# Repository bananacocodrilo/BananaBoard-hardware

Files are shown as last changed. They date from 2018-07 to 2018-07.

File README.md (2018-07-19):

# BananaBoard-hardware

This is still under development and subject to changes.

Split wireless keyboard based on the [mitosis](https://github.com/reversebias/mitosis-hardware) and the [chimera](https://github.com/GlenPickle/Chimera).

The goal is to make boards easy to solder and compatible with existing cases for popular keybards as "let's split" or "iris keyboard" and a miniboard for handwired builds.

I'll also publish a fork of their firmware as well since I need to use a matrix configuration instead of a "pin per switch", furthermore I'll add battery measure and underglow leds.

I haven't make a PCB in a while and is my first time using kicad so I'm learning as a I go.

Current state:
-
 - "Finished" schematic: I like how it is right now and it will probably stay like this.
 - "Finished" a first version for handwired builds (it fits in 24mmx50mm so I added 2 per board).
 - Second version of the 40% split PCB, I think is compatible with the "lets split" case but it isn't reversible so I'll need to create the "right hand" too.

Next steps: 
-
 - Decide a footprint for the switches (right now I'm not sure which footprint works with which switch).
 - (Currently working) Create the right hand of the lets split.
 - Investigate other lipo charger circuits. I've ordered a few cheap micro usb ones since I couldn't find reliable size info.
 - Start the firmware modifications.

Ortho 40% board (left hand):
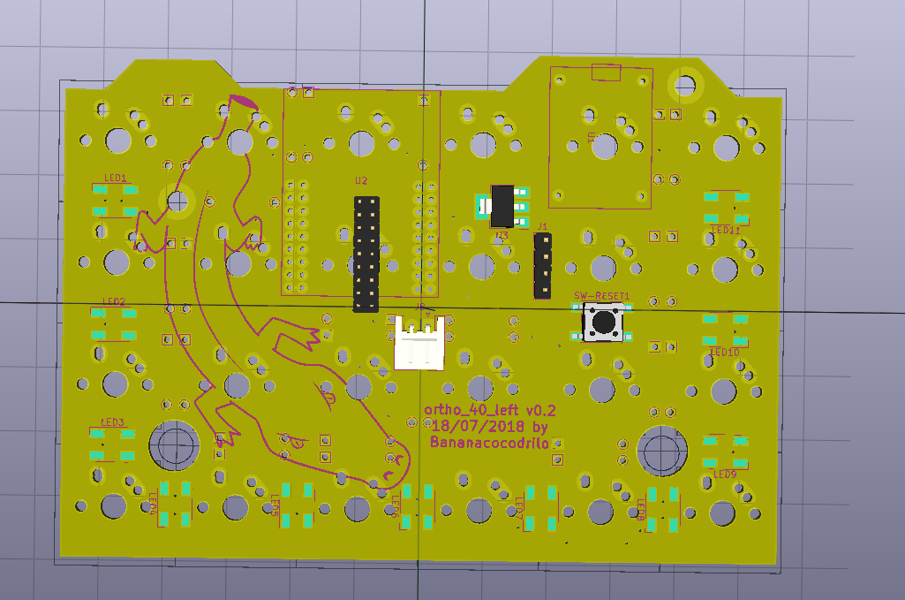
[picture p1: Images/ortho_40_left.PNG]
pcb image


Handwired keyboards board:
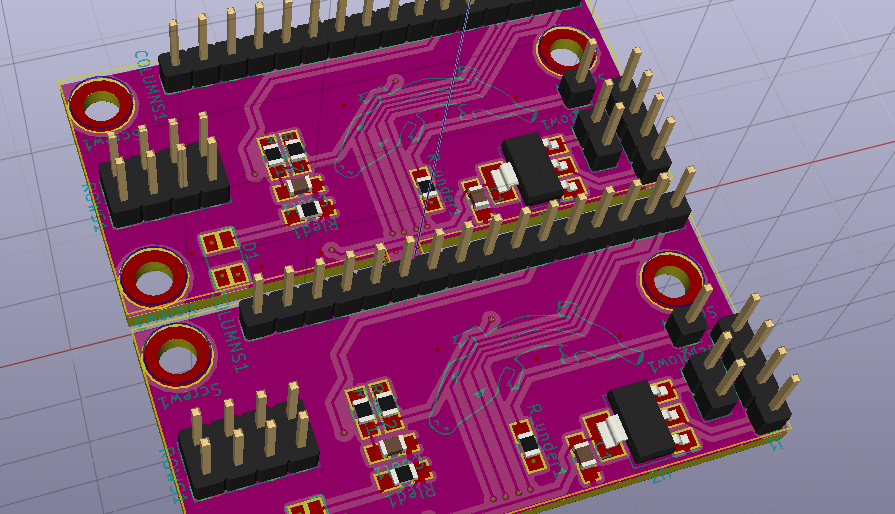
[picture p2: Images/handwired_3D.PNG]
handwired


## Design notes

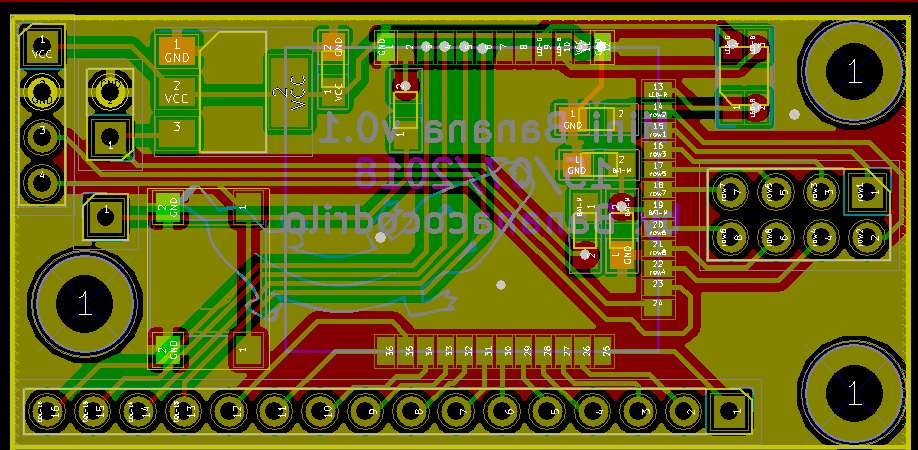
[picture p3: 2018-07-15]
Images/handwired.PNG

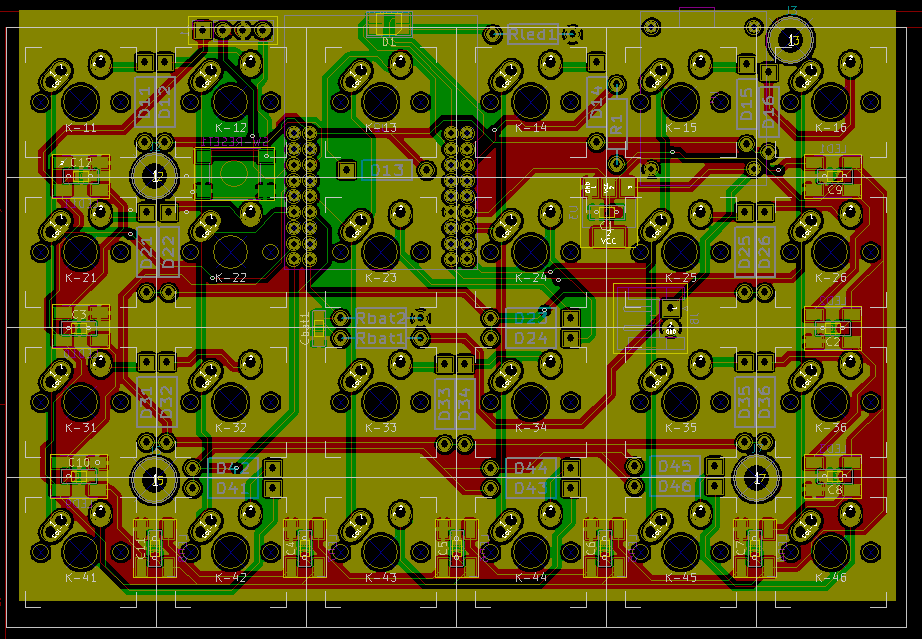
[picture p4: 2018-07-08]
Images/pcb.PNG

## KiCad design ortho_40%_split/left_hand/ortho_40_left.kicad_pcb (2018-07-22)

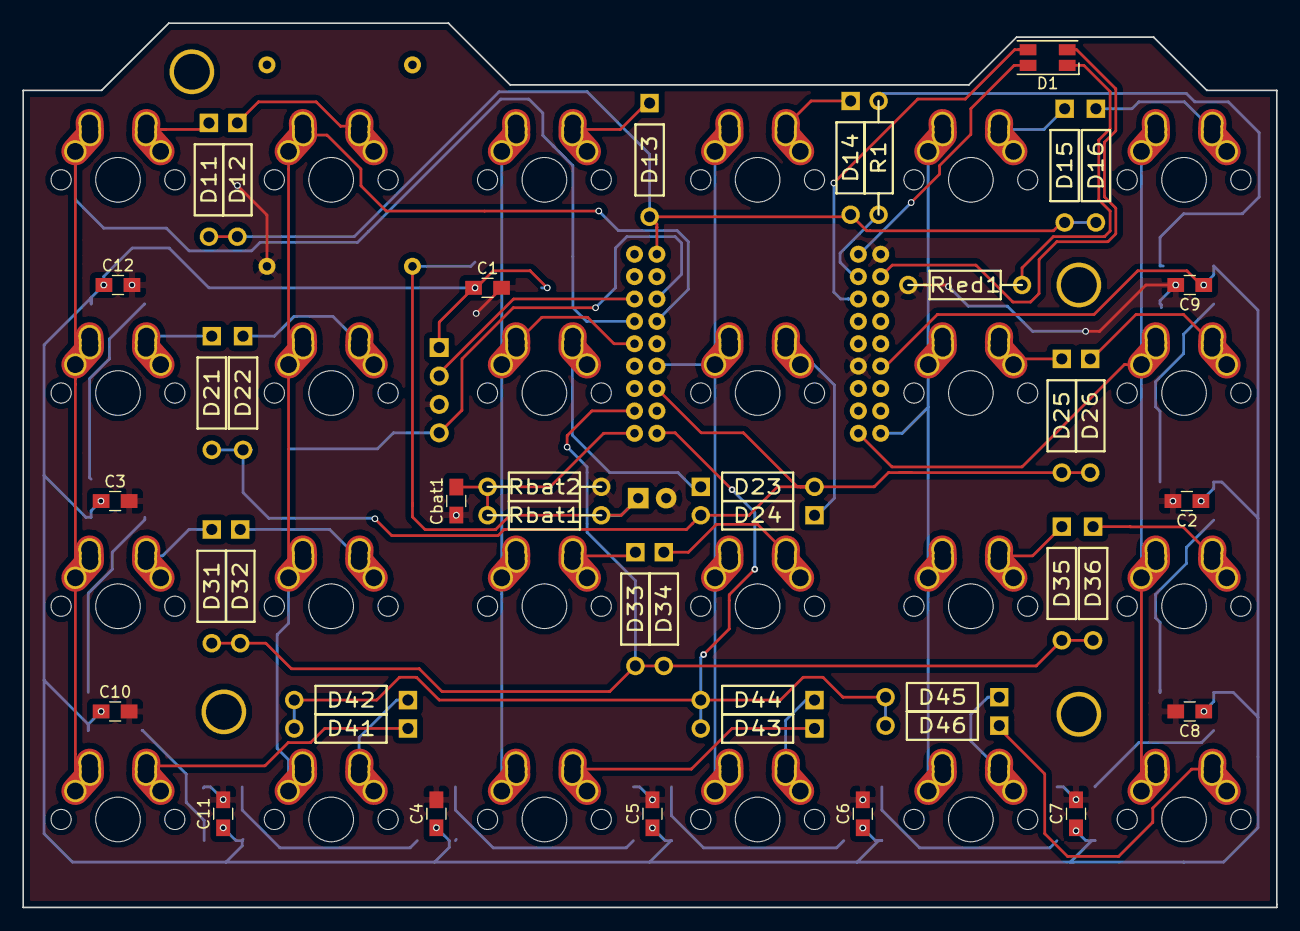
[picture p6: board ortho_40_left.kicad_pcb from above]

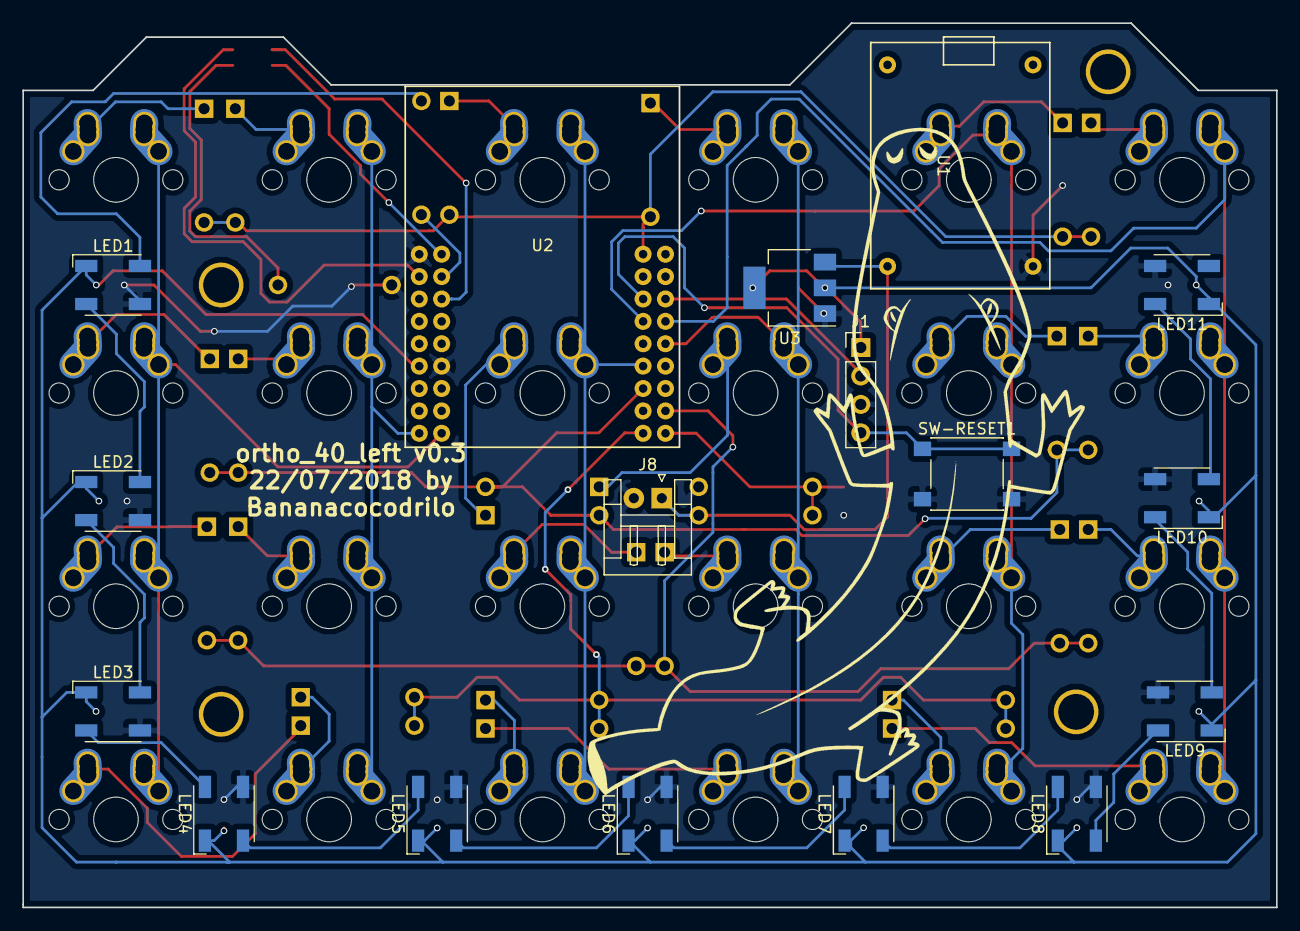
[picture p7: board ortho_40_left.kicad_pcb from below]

Board: 2 copper layers, 112.0 x 79.0 mm, 87 parts (17 on the bottom side), 56 nets.

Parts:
C1: 47uF; C_0805_HandSoldering
C2, C3, C4, C5, C6, C7, C8, C9, C10, C11, C12: 0.1uF; C_0805_HandSoldering
Cbat1: 22n; C_0805_HandSoldering
D1: LED_BAT; LED_RGB_1210
D11, D12, D13, D14, D15, D16, D21, D22, D23, D24, D25, D26, D31, D32, D33, D34, D35, D36, D41, D42, D43, D44, D45, D46: D; DIODE
J1: prog_pins; Pin_Header_Straight_1x04_Pitch2.54mm
J2, J3, J5, J7: Conn_01x01; HOLE_M3
J8: Conn-Battery; JST_EH_S02B-EH_02x2.50mm_Angled
K-11, K-12, K-13, K-14, K-15, K-16, K-21, K-22, K-23, K-24, K-25, K-26, K-31, K-32, K-33, K-34, K-35, K-36, K-41, K-42, K-43, K-44, K-45, K-46: KEYSW; Hybrid_PCB_100H_Dual_hole
LED1, LED2, LED3, LED4, LED5, LED6, LED7, LED8, LED9, LED10, LED11: WS2812B; LED_RGB_5050-4
R1: 470; RESISTOR
Rbat1: 10M; RESISTOR
Rbat2: 2.2M; RESISTOR
Rled1: 470; RESISTOR
SW-RESET1: SW_PUSH; SW_SPST_PTS645
U1: cargador-USB; cargador-mini-usb
U2: core51822; core51822-through-hole
U3: LM1117-3.3; SOT-223-3_TabPin2

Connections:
BAT-M: Cbat1.2, Rbat1.1, Rbat2.2, U2.36
GND: C1.2, C2.2, C3.2, C4.2, C5.2, C6.2, C7.2, C8.2, C9.2, C10.2, C11.2, C12.2, Cbat1.1, J1.3, J8.2, LED1.3, LED2.3, LED3.3, LED4.3, LED5.3, LED6.3, LED7.3, LED8.3, LED9.3, LED10.3, LED11.3, Rbat2.1, Rled1.1, SW-RESET1.2, U1.3, U2.1, U2.12, U3.1
LED-B: D1.4, U2.2
LED-G: D1.3, U2.6
LED-R: D1.2, U2.3
unnamed: D1.1, Rled1.2
unnamed: D11.2, K-11.2
unnamed: D12.2, K-12.2
unnamed: D13.2, K-13.2
unnamed: D14.2, K-14.2
unnamed: D15.2, K-15.2
unnamed: D16.2, K-16.2
unnamed: D21.2, K-21.2
unnamed: D22.2, K-22.2
unnamed: D23.2, K-23.2
unnamed: D24.2, K-24.2
unnamed: D25.2, K-25.2
unnamed: D26.2, K-26.2
unnamed: D31.2, K-31.2
unnamed: D32.2, K-32.2
unnamed: D33.2, K-33.2
unnamed: D34.2, K-34.2
unnamed: D35.2, K-35.2
unnamed: D36.2, K-36.2
unnamed: D41.2, K-41.2
unnamed: D42.2, K-42.2
unnamed: D43.2, K-43.2
unnamed: D44.2, K-44.2
unnamed: D45.2, K-45.2
unnamed: D46.2, K-46.2
unnamed: J1.2, U2.24
unnamed: J1.4, SW-RESET1.1, U2.23
unnamed: J8.1, Rbat1.2, U1.2, U3.3
unnamed: LED1.2, LED2.4
unnamed: LED1.4, R1.1
unnamed: LED2.2, LED3.4
unnamed: LED3.2, LED4.4
unnamed: LED4.2, LED5.4
unnamed: LED5.2, LED6.4
unnamed: LED6.2, LED7.4
unnamed: LED7.2, LED8.4
unnamed: LED8.2, LED9.4
unnamed: LED10.2, LED11.4
VCC: C1.1, C2.1, C3.1, C4.1, C5.1, C6.1, C7.1, C8.1, C9.1, C10.1, C11.1, C12.1, J1.1, LED1.1, LED2.1, LED3.1, LED4.1, LED5.1, LED6.1, LED7.1, LED8.1, LED9.1, LED10.1, LED11.1, U2.11, U3.2
col-1: K-11.1, K-21.1, K-31.1, K-41.1, U2.26
col-2: K-12.1, K-22.1, K-32.1, K-42.1, U2.25
col-3: K-13.1, K-23.1, K-33.1, K-43.1, U2.28
col-4: K-14.1, K-24.1, K-34.1, K-44.1, U2.29
col-5: K-15.1, K-25.1, K-35.1, K-45.1, U2.17
col-6: K-16.1, K-26.1, K-36.1, K-46.1, U2.18
row-1: D11.1, D12.1, D13.1, D14.1, D15.1, D16.1, U2.19
row-2: D21.1, D22.1, D23.1, D24.1, D25.1, D26.1, U2.31
row-3: D31.1, D32.1, D33.1, D34.1, D35.1, D36.1, U2.34
row-4: D41.1, D42.1, D43.1, D44.1, D45.1, D46.1, U2.35
underglow: R1.2, U2.4
underglowAux: LED9.2, LED10.4

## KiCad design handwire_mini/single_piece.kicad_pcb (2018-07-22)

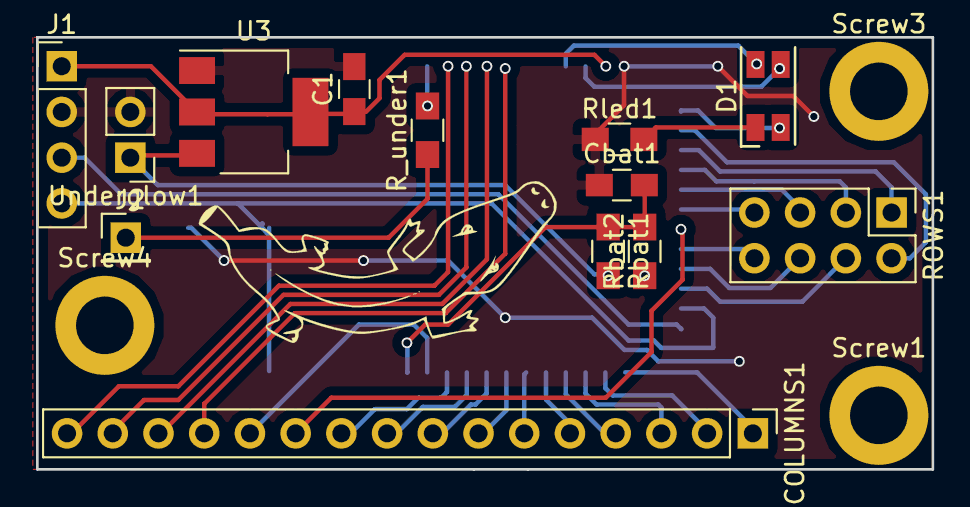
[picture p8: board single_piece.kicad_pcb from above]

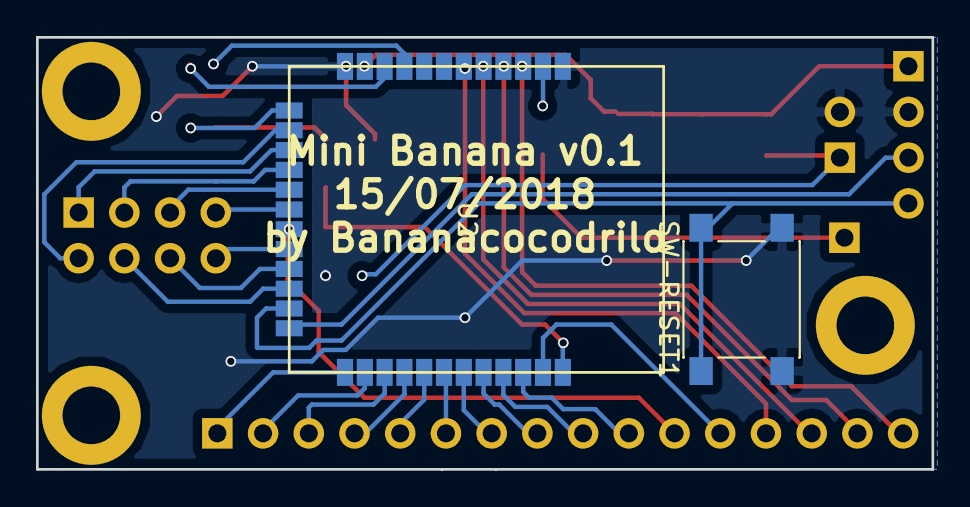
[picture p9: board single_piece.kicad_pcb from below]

Board: 2 copper layers, 49.8 x 24.0 mm, 18 parts (2 on the bottom side), 36 nets.

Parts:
C1: 47uF; C_0805_HandSoldering
COLUMNS1: Pin_Header_Straight_1x16_Pitch2.54mm
Cbat1: 22n; C_0805_HandSoldering
D1: LED_BAT; LED_RGB_1210
J1: prog_pins; Pin_Header_Straight_1x04_Pitch2.54mm
J2: Lipo; Pin_Header_Straight_1x02_Pitch2.54mm
ROWS1: ROWS; Pin_Header_Straight_2x04_Pitch2.54mm
R_under1: 470; R_0805_HandSoldering
Rbat1: 10M; R_0805_HandSoldering
Rbat2: 2.2M; R_0805_HandSoldering
Rled1: 470; R_0805_HandSoldering
SW-RESET1: SW_PUSH; SW_SPST_PTS645
Screw1, Screw3, Screw4: Screw; MountingHole_3.2mm_M3_ISO14580_Pad
U2: core51822; cpre51822-smd
U3: LM1117-3.3; SOT-223-3_TabPin2
Underglow1: TO_WS2812b; Pin_Header_Straight_1x01_Pitch2.54mm

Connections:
BAT-M: Cbat1.2, Rbat1.1, Rbat2.2, U2.36
COL-13: COLUMNS1.13, U2.6
COL-14: COLUMNS1.14, U2.5
COL-15: COLUMNS1.15, U2.4
COL-16: COLUMNS1.16, U2.3
GND: C1.2, Cbat1.1, J1.2, J2.2, Rbat2.1, Rled1.1, SW-RESET1.2, U2.1, U2.12, U3.1
LED-B: D1.3, U2.10
LED-G: D1.4, U2.9
LED-R: D1.2, U2.13
unnamed: COLUMNS1.1, U2.25
unnamed: COLUMNS1.2, U2.26
unnamed: COLUMNS1.3, U2.27
unnamed: COLUMNS1.4, U2.28
unnamed: COLUMNS1.5, U2.29
unnamed: COLUMNS1.6, U2.30
unnamed: COLUMNS1.7, U2.31
unnamed: COLUMNS1.8, U2.32
unnamed: COLUMNS1.9, U2.33
unnamed: COLUMNS1.10, U2.34
unnamed: COLUMNS1.12, U2.35
unnamed: D1.1, Rled1.2
unnamed: J1.3, U2.24
unnamed: J1.4, SW-RESET1.1, U2.23
unnamed: J2.1, Rbat1.2, U3.3
unnamed: R_under1.1, Underglow1.1
unnamed: R_under1.2, U2.2
VCC: C1.1, J1.1, U2.11, U3.2
col-11: COLUMNS1.11, U2.19
row1: ROWS1.1, U2.15
row2: ROWS1.2, U2.14
row3: ROWS1.3, U2.16
row4: ROWS1.4, U2.22
row5: ROWS1.5, U2.17
row6: ROWS1.8, U2.20
row7: ROWS1.7, U2.18
row8: ROWS1.6, U2.21

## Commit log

2018-07-08 Firts version
    Finished untested version.
    DRC pases ok
    [bananaboard.kicad_pcb, bananaboard.sch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]
2018-07-08 Moved screw hole
    [bananaboard.kicad_pcb]
2018-07-08 added images folder, moved diode and mounting hole
    [bananaboard.kicad_pcb]
2018-07-15 Many changes, see desc
    Moved previous board to ortho_40% folder, also created a new board for handwired builds.
    Now working in modifying the ortho board to be compatible with the lets split cases
    [banana_handwired.kicad_pcb, banana_handwired.sch, bananaboard.kicad_pcb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]
2018-07-17 added gerber files
    [banana_handwired-B.Cu.gbl, banana_handwired-B.Mask.gbs, banana_handwired-B.SilkS.gbo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]
2018-07-18 updated pcb to fit lets split case
    I moved the files into a new folder "left" since it looks that it wont be fully compatible with the case thus I'll need to create another version for the right hand
    [bananaboard.kicad_pcb, ortho_40_left.kicad_pcb, ortho_40_left.sch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]
2018-07-22 working on right hand
    [ortho_40_left.kicad_pcb, ortho_40_right.kicad_pcb, ortho_40_right.sch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]
